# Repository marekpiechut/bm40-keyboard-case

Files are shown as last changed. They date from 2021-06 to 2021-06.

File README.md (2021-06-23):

# bm40-keyboard-case
A 3d printable case for BM40 RGB mechanical keyboard PCB.
It's a super slim case, just wraps pcb and adds minimal space around.

It has quite a few features though:
- Mounting holes and designs for angling feets (if you like your keeb to be a bit angled)
- Grooves for 8mm adhesive silicone/rubber feet pads (also on angling feets)
- Nice looking hexagonal holes for underglow LEDs
- Holes for PCB mounting
- Hole to access Reset pads on PCB
- Minimal USB connector hole
- Switch plate for better stability (also in split and unsplit versions)
- Available in unsplit and split versions (for smaller 3d printers)

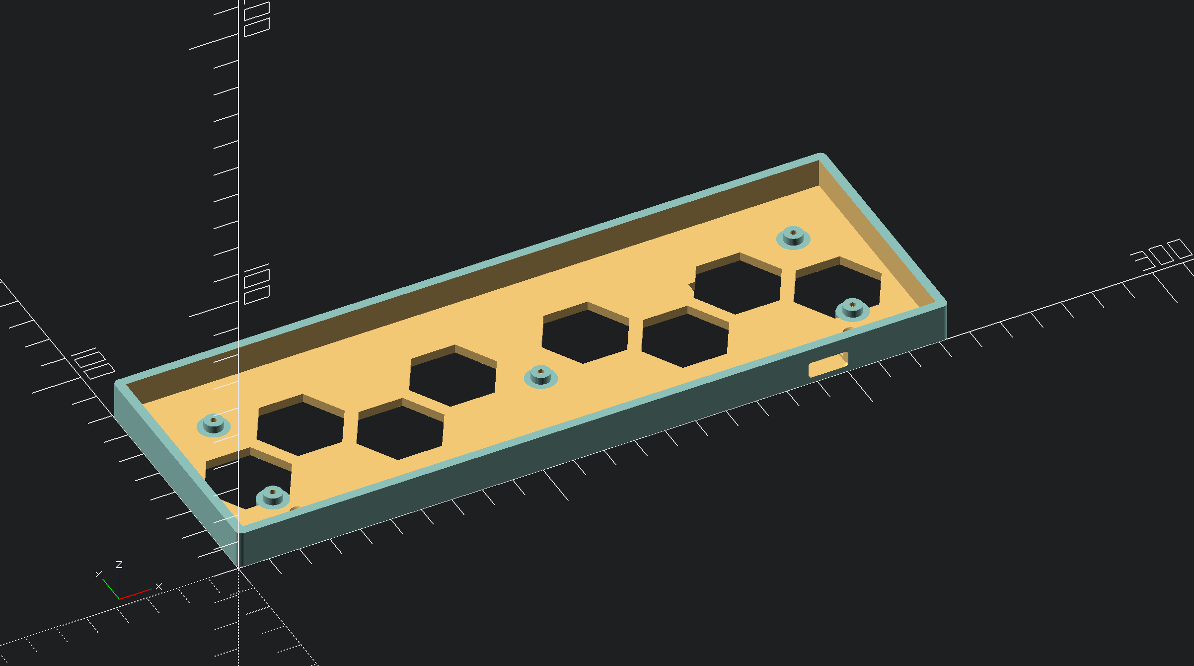
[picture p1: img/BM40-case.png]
3d Model Screen 3d Render of the case


## How to get it

Get STL files here:

[https://www.thingiverse.com/thing:4892596](https://www.thingiverse.com/thing:4892596)

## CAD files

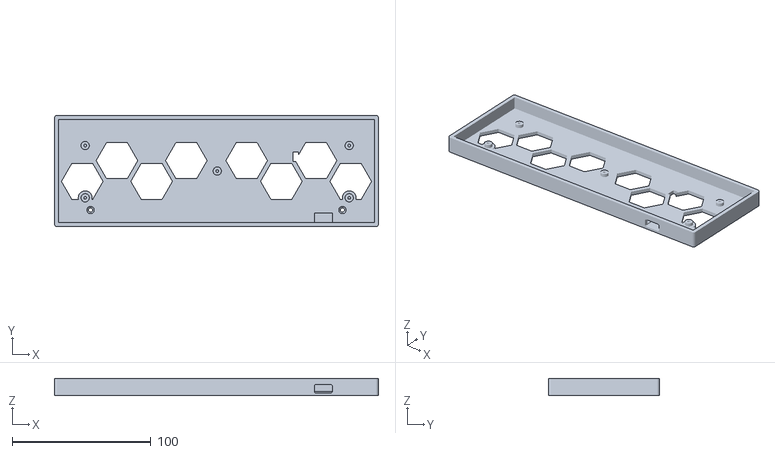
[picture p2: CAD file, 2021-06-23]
BM40-case.stl
233.5 x 80.3 x 12.5

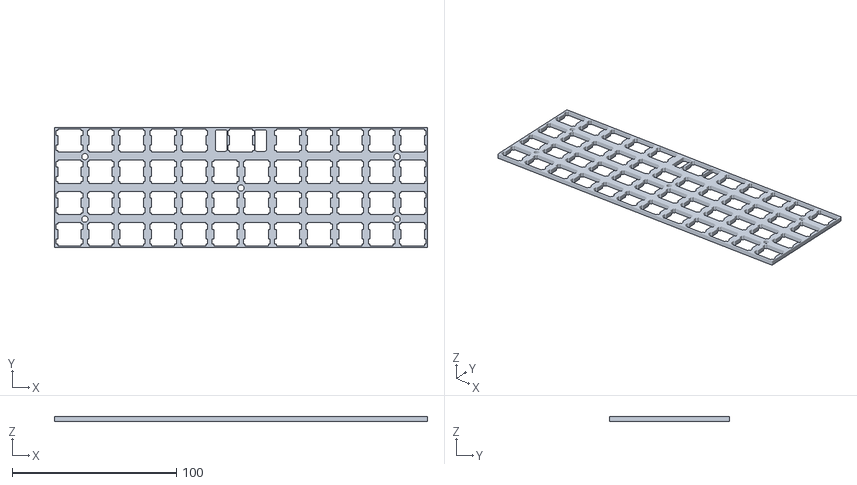
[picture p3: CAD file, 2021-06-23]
BM40-plate.stl
227.0 x 73.3 x 3.00

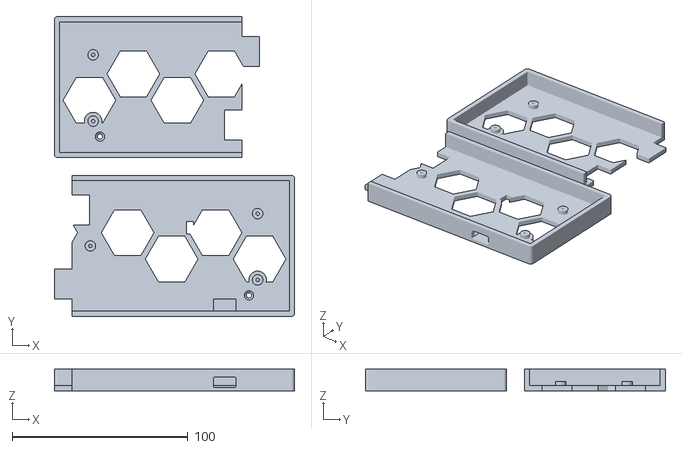
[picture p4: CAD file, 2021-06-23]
BM40-case-split.stl
136.8 x 170.6 x 12.5

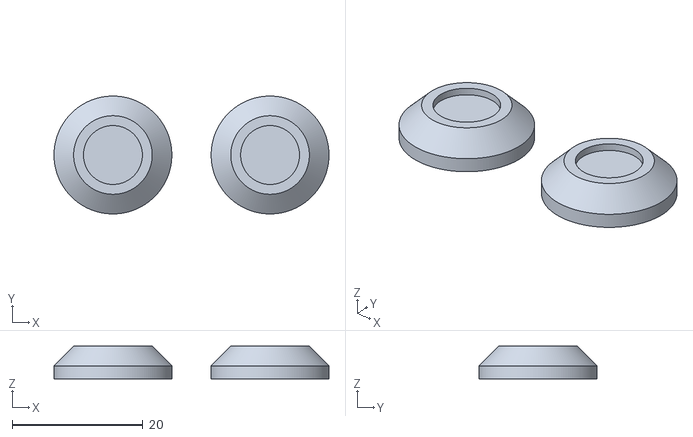
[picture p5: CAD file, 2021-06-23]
BM40-leg-extenders.stl
42.0 x 18.0 x 5.00

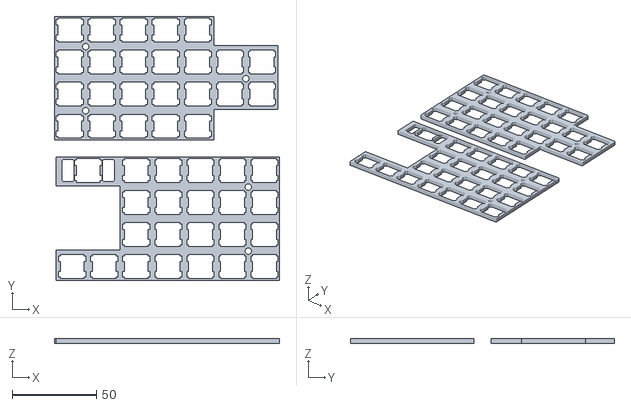
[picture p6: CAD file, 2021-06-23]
BM40-plate-split.stl
133.5 x 156.6 x 3.00

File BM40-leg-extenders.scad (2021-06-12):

$fa = 1;
$fs = 0.4;

height = 5;

module leg_extender() {
	difference(){
		union() {
			cylinder(2, 9, 9);
			translate([0, 0, 2]) cylinder(height - 2, 9, 6);
		}
		translate([0, 0, -1]) cylinder(height - 1, 1, 1);
		translate([0, 0, height - 1]) cylinder(2, 4.5, 4.5);
	}
}

leg_extender();
translate([24, 0, 0]) leg_extender();

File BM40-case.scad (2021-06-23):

include <roundedCube.scad>

split=true;

$fa = 1;
$fs = 0.4;

thickness=3;
padding=1;
pcb_edge=thickness + padding / 2;
pcb=[226.5,73.3,10.5];
inside=[pcb[0]+padding, pcb[1]+padding, pcb[2]+padding + 10];
outside=[inside[0]+thickness*2, inside[1]+thickness*2, pcb[2]+2];
usb_depth=10;
pcb_depth=8.4;
hex_diameter=30;

module screw_mount(x, y , z) {
	translate([x, y, z])
	difference(){
		union() {
			cylinder(2.5, 3, 3);
			translate([0, 0, -3]) cylinder(3, 5, 5);
		}
		translate([0, 0, 1]) cylinder(4, 1, 1);
	}
}

module leg_hole(x, y) {
	translate([x, y, -1]) cylinder(2, 4.5, 4.5);
}

module usb_connector(x) {
	translate([x, 1, 2]) cube([13, 9, 2]);
	translate([x, -1, 2]) roundedCube([13, thickness + 2, 6], 1, false, true, true);
}

module reset_button(x, y) {
	 translate([x, y, -1]) cube([4, 7, 5]);
}

module extender_leg_hole(x, y) {
	translate([x, y, -1]) union() {
		cylinder(5, 1.5, 1.5);
		translate([0, 0, 3]) cylinder(1.3, 1.5, 3);
	}
}

module logo() {
	linear_extrude(height = 1, center = true)
	rotate([180, 0, 0])
	resize([12, 15, 0])
	import("dayone-logo.svg", center = true);
}

module button_row(cols, height) {
	for (i=[0:1:4]) {
		translate([i*19,0,0]) cube(14, 14, height);
	}
}




module box() {
	difference()
	{
		roundedCube(outside, 2);
		translate([thickness, thickness, 3]) cube(inside);
		usb_connector(outside[0] - pcb_edge - 42.8);
		reset_button(172, 47);
		extender_leg_hole(outside[0]-26, 12);
		extender_leg_hole(26, 12);
		translate([20, outside[1] / 2, 0]) led_holes();
		translate([outside[0] - 20, outside[1] / 2, 0]) mirror([1, 0, 0]) led_holes();
	};
}

module splitter() {
	union() {
		translate([0, -10, -10]) cube([170, 120, 50]);
		translate([150, 30, -10]) cube(30);
	}
}

module hex(diameter, height) {
	cylinder(d = diameter, h = height, center = true, $fn = 6);
}

module led_holes() {
	translate([0, -15/2, 0]) {
		translate([0, 0, 0]) hex(hex_diameter, 10);
		translate([25, 15, 0]) hex(hex_diameter, 10);
		translate([50, 0, 0]) hex(hex_diameter, 10);
		translate([75, 15, 0]) hex(hex_diameter, 10);
	}
}

module screw_mounts() {
	screw_mount(pcb_edge + 18.6, pcb_edge + 17.3, 3);
	screw_mount(pcb_edge + 18.6, outside[1] - pcb_edge - 18.3, 3);
	screw_mount(outside[0] - pcb_edge - 17.6, pcb_edge + 17.3, 3);
	screw_mount(outside[0] - pcb_edge - 17.6, outside[1] - pcb_edge - 18.3, 3);
	screw_mount(pcb_edge + 113.8, pcb_edge + 36.6, 3);
}

module leg_holes() {
	leg_hole(10, 15);
	leg_hole(15, outside[1]-15);
	leg_hole(outside[0]-10, 15);
	leg_hole(outside[0]-15, outside[1]-15);
}

module the_case() {
	difference() {
		union() {
			box();
			screw_mounts();
		}
		leg_holes();
		translate([outside[0] / 2, 22, 0]) logo();
	}
}


module splitter() {
	union() {
		difference() {
			translate([-1, -1, -1]) cube([outside[0] / 2 - 9, outside[1] + 2, outside[2] + 2]);
			translate([outside[0] / 2 - 20, 10, -1 ]) cube([10, 17, outside[2] + 2]);
		}
		translate([outside[0] / 2 - 10, 52, -1 ]) cube([10, 17, outside[2] + 2]);
	}
}
module splitted_case() {
	translate([-outside[0] / 2 + 20, 0, 0]) difference() {
		the_case();
		splitter();
	}
	translate([0, outside[1] + 10, 0]) intersection() {
		the_case();
		splitter();
	}
}

if(split)
	splitted_case();
else
	the_case();

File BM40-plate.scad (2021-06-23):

include <roundedCube.scad>

split=false;

$fa = 1;
$fs = 0.4;

button_spacing = 19;
padding=0.5;
pcb=[226.5,73.3,10.5];
inside=[pcb[0]+padding, pcb[1], 3];


module button() {
	union() {
		cube([14.1, 14.1, 10]);
		translate([-1, 1, 0]) cube([2, 3.2, 10]);
		translate([-1, 10, 0]) cube([2, 3.2, 10]);
		translate([13.2, 1, 0]) cube([2, 3.2, 10]);
		translate([13.2, 10, 0]) cube([2, 3.2, 10]);
	}
}

module button_2u() {
	union() {
		translate([(33 - 14) / 2, 0, 0]) button();
		translate([1, 0.5, 0]) roundedCube([7, 13, 10]);
		translate([33 - 7 - 1, 0.5, 0]) roundedCube([7, 13, 10]);
//		cube([33, 14, 4]);	
	}
}

module buttons(rows, cols) {
	for (i=[0:1:cols - 1]) {
		for (j=[0:1:rows - 1]) {
			translate([i*button_spacing,j*button_spacing, -2]) button();
		}
	}
}

module grid() {
	buttons(3, 12);
	translate([0, button_spacing*3, 0]) buttons(1, 5);
	translate([button_spacing * 7, button_spacing*3, 0]) buttons(1, 5);
	translate([button_spacing * 5, button_spacing*3, -2]) button_2u();
	translate([button_spacing * 7, button_spacing*3, 0]) buttons(1, 5);
}

module screw_mount(x, y , z) {
	translate([x, y, z]) cylinder(10, 1.9, 1.9);
}

module the_plate() {
	difference() {
		roundedCube(inside, 0.4);
		translate([2, 1.2, 0]) grid();
		screw_mount(2 + 16.5, 1.4 + 16, -1);
		screw_mount(2 + 16.5, 1.4 + 16 + 2 * 19, -1);
		screw_mount(2 + 16.5 + 10 * 19, 1.4 + 16, -1);
		screw_mount(2 + 16.5 + 10 * 19, 1.4 + 16 + 2 * 19, -1);
		screw_mount(2 + 16.5 + 5 * 19, 1.4 + 16 + 19, -1);
	}
}

module splitter() {
	translate([-1, -1, -1]) union() {
		cube([inside[0] / 2 - 18, inside[1] + 2, inside[2] + 2]);	
		translate([inside[0] / 2 - 18, 19, 0])cube([38, 38, inside[2] + 2]);
	}
}

module splitted_plate() {
	translate([-inside[0] / 2 + 20, 0, 0]) difference() {
		the_plate();
		splitter();
	}
	translate([0, inside[1] + 10, 0]) intersection() {
		the_plate();
		splitter();
	}
}

if(split)
	splitted_plate();
else
	the_plate();

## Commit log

2021-06-10 Case + leg extenders
    [BM40-case.scad, BM40-leg-extenders.scad, BM40-plate.scad]
2021-06-10 Improve split - more rigid glueing area
    [BM40-case.scad]
2021-06-10 Splitable plate (untested), split as a parameter)
    [BM40-case.scad, BM40-plate.scad]
2021-06-10 Add license
    [BM40-case.scad]
2021-06-11 Small corrections in screws and reset placement
    [BM40-case.scad]
2021-06-11 Larger adhesive legs holes
    [BM40-case.scad, BM40-leg-extenders.scad]
2021-06-12 Smaller screw holes in leg extender
    [BM40-leg-extenders.scad]
2021-06-22 High profile plate with button grooves
    [BM40-plate.scad]
2021-06-23 Small fixes in plate
    [BM40-plate.scad]
2021-06-23 Revert "Small corrections in screws and reset placement"
    This reverts commit d713cd4d8fa1d27880e68faf138703b21856c643.
    [BM40-case.scad]
2021-06-23 Fix reset switch position
    [BM40-case.scad]
2021-06-23 Rev 1.0
    [BM40-case-split.stl, BM40-case.scad, BM40-case.stl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]
